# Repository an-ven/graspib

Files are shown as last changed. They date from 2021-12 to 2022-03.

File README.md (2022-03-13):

# GrasPiB
GPIB interface board for Raspberry Pi, designed to work with [linux-gpib](https://linux-gpib.sourceforge.io/) gpio bitbang driver. Extra features include: RS232 serial interface, voltage regulator, fan mount and I2C conector.

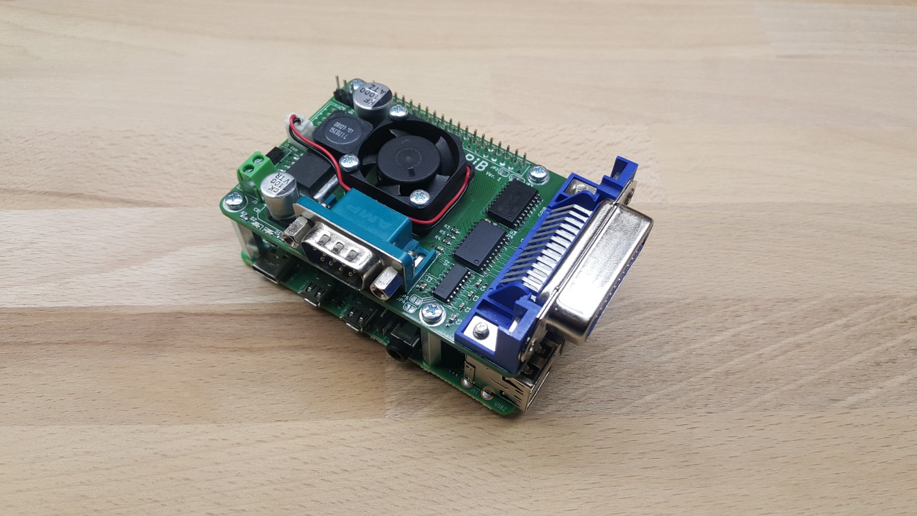
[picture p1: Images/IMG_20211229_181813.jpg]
GrasPiB


## Features
* Active GPIB interface circuit using SN7516x bus driver ICs
* RS232 serial interface (MAX3232 level converter), with optionally configurable RTS and CTS lines
* Step down voltage regulator (LM2576) for use with higher voltage power supplies (7-35VDC)
* 25mm cooling fan mounting holes and 2pin JST-PH connector for power
* I2C break out connector with one extra GPIO line (5pin JST-PH connector)
* Stacks on top of a Raspberry Pi

## Configuration options

**JP7 Power supply selection:**

* Close pins 1-2: Power from J5 screw terminal trough onboard regulator circuit (7-35VDC input)
* Close pins 2-3: Power from J5 screw terminal bypassing onboard regulator circuit (5VDC input only !!)
* Leave Open: Power from Raspberry Pi power input USB connector, GrasPiB regulator circuit is isolated

**JP6 Output Voltage select on I2C breakout connector**

* Close pins 1-2: 3,3V on J4 pin 1
* Close pins 2-3: 5V on J4 pin 1

**Enabling RS232 CTS and RTS lines:**

* Close jumpers JP1, JP2, JP4 and JP5, open JP3 positions 1-2 and close positions 2-3
* This change also needs the GPIB DIO3 signal to be reassigned from GPIO16 to GPIO21 (linux-gpib driver code modifications needed)

## Linux-gpib setup instructions

(following instructions were tested on a fresh Raspberry Pi OS Lite image)

0. Setup and configure OS on Raspberry Pi
    * Do as you would with a fresh OS image (passwords, networking, services, communication ports...)

1. Install build tools and dependencies
    * Build tools: `$ sudo apt install build-essential autoconf automake libtool flex bison`
    * RPi kernel headers: `$ sudo apt install raspberrypi-kernel-headers`
    * Python3 headers: `$ sudo apt install python3-dev`

2. Download linux-gpib source files
    * Get release archives (4.3.4 or later) from [https://sourceforge.net/projects/linux-gpib/files](https://sourceforge.net/projects/linux-gpib/files)
    * or get the latest source from [https://sourceforge.net/p/linux-gpib/code/HEAD/tree/](https://sourceforge.net/p/linux-gpib/code/HEAD/tree/)

3. Build and install kernel drivers
    * Enter linux-gpib-kernel directory `$ cd linux-gpib-src-dir/linux-gpib-kernel`
    * Build kernel module by running make `$ make`
    * Install kernel module `$ sudo make install`
    * Update kernel module list `$ sudo depmod -a`
    * Load gpib_bitbang kernel module `$ sudo modprobe gpib_bitbang`
    * Now there should be some `gpib*` devices in `/dev`
    * Make the module loads on boot by adding `gpib_bitbang` line to `/etc/modules-load.d/modules.conf`

**When Raspberry Pi OS kernel gets upgraded, linux-gpib kernel module also needs to be rebuilt and reinstalled.**
Basically just repeat above `make` and `make install` steps when kernel gets upgraded...

4. Build and install user space tools
    * Enter linux-gpib-user directory: `$ cd linux-gpib-src-dir/linux-gpib-user`
    * If building from svn checkout first run bootstrap script: `$ ./bootstrap`
    * Run configure script: `$ ./configure` (run `$ ./configure --help` to list additional options)
    * Build user space tools by running make: `$ make`
    * Install user space tools: `$ sudo make install`
    * Make sure that shared library directory (default: `/usr/local/lib/`) is listed in: `/etc/ld.so.conf.d/`
    * Then run: `$ sudo ldconfig`

5. Configure GPIB interface
    * Open gpib.conf configuration file `$ sudo nano /usr/local/etc/gpib.conf` (default location)
    * Set `board_type = "gpib_bitbang"` and other relevant settings (for details refer to included [`gpib.conf`](extra/gpib.conf) file, [linux-gpib documentetion](https://linux-gpib.sourceforge.io/doc_html/configuration-gpib-conf.html) and included template file `linux-gpib-src-dir/linux-gpib-user/util/template/gpib.conf`)
    * Run gpib_config so the driver reads the configuration file `$ sudo gpib_config --minor 0`
    * Make the last command execute on every startup using crontab entry:
        - Edit crontab for root user: `$ sudo crontab -e`
        - Add line the following line to cron tab file: `@reboot /usr/local/sbin/gpib_config --minor 0`

6. Enable non root users to use GPIB interface without sudo
    - Add new `gpib` system group: `$ sudo groupadd -r gpib`
    - Append your_user_name to `gpib` supplementary group: `$ sudo usermod -a -G gpib your_user_name`
    - Create [`/etc/udev/rules.d/99-gpib.rules`](extra/99-gpib.rules) file and add line: `SUBSYSTEM=="gpib_common", GROUP="gpib", MODE="0660"`
    - Reboot system to apply changes (udevadm utility can also be used, but reboot is dead simple to remember)
    - Test by running `ibtest` without sudo

Above instructions should result in an environment with a functional GPIB interface, C headers and python bindings, ready for use.

## Enabling RS232 Hardware flow control

### Hardware setup:

On the Raspberry Pi CTS and RTS signals are mapped to pins GPIO16 and GPIO17. By default, linux-gpib bitbang driver uses GPIO16 for GPIB DIO3 signal. In order to free up GPIO16, the DIO3 signal can be rewired to GPIO21 by **opening** positions **1-2** (cut traces between pads) and **closing** positions **2-3** on the solder jumper JP3.

By default, CTS and RTS signals are disconnected from the RS232 level converter chip. To connect the CTS and RTS lines, solder jumpers **JP1**, **JP2**, **LP4** and **JP5** need to be **closed**.

Note also, that the extra GPIO17 line on the I2C break out connector J4 can't be used for other purposes when system is configured for RS232 hardware flow control.

### Software setup:

1. Because GPIB signal DIO3 was rewired in hardware to GPIO21, this change needs to reflected in the linux-gpib bitbang driver source code. The source file in question is: `[linux-gpib-sorce-dir]/linux-gpib-kernel/drivers/gpib/gpio/gpib_bitbang.c`, where the signal pairing section needs to be modified as shown below. With the modification done, the linux-gpib driver needs to be compiled as described in step 3 of the "Linux-gpib setup instructions" section of this document.

```
/**********************************************
 *  Signal pairing and pin wiring between the *
 *  Raspberry-Pi connector and the GPIB bus   *
 *                                            *
 *               signal           pin wiring  *
 *            GPIB  Pi-gpio     GPIB  ->  RPi *
**********************************************/
typedef enum {
        D01_pin_nr =  20,     /*   1  ->  38  */
        D02_pin_nr =  26,     /*   2  ->  37  */
//      D03_pin_nr =  16,     /*   3  ->  36  ORIGINAL AND COMMENTED OUT */
        D03_pin_nr =  21,     /*   3  ->  40  MODIFIED TO AVOID CONFLICT WITH CTS SIGNAL */
        D04_pin_nr =  19,     /*   4  ->  35  */
        D05_pin_nr =  13,     /*  13  ->  33  */
        D06_pin_nr =  12,     /*  14  ->  32  */
        D07_pin_nr =   6,     /*  15  ->  31  */
        D08_pin_nr =   5,     /*  16  ->  29  */
        EOI_pin_nr =   9,     /*   5  ->  21  */
        DAV_pin_nr =  10,     /*   6  ->  19  */
        NRFD_pin_nr = 24,     /*   7  ->  18  */
        NDAC_pin_nr = 23,     /*   8  ->  16  */
        IFC_pin_nr =  22,     /*   9  ->  15  */
        SRQ_pin_nr =  11,     /*  10  ->  23  */
        _ATN_pin_nr = 25,     /*  11  ->  22  */
        REN_pin_nr =  27,     /*  17  ->  13  */
...

```

2. Next the [`uart-ctsrts.dtbo`](extra/uart-ctsrts.dtbo) file (included in extra directory) needs to be copied in to the `/boot/overlays` directory and add the following lines need to be added to the `/boot/config.txt` file:

```
enable_uart=1
dtoverlay=disable-bt
dtoverlay=uart-ctsrts
```

3. Reboot the system to apply changes.

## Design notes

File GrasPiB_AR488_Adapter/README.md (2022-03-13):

# GrasPiB Arduino Micro adapter

A simple adapter board for connecting the GrasPiB Raspberry Pi hat to an Arduino Micro running the [AR488 firmware](https://github.com/Twilight-Logic/AR488).

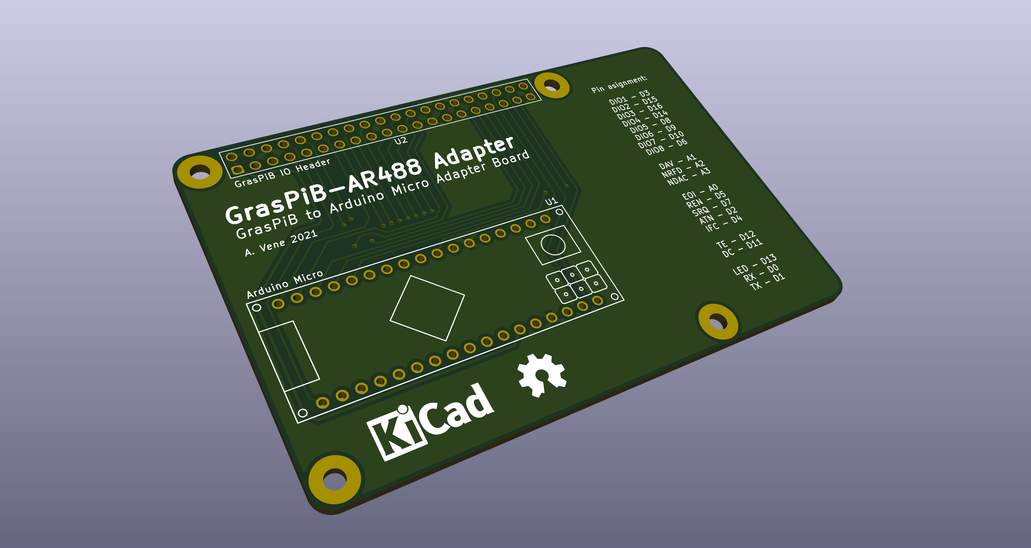
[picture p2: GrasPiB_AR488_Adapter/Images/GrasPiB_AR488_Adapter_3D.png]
GrasPiB_AR488_Adapter


## AR488 configuration

Pin assignment is compatible with the default AR488, except for the TE and DC control signals for the SN7516x bus drivers, which need to be enabled in the [`AR488_Config.h`](https://github.com/Twilight-Logic/AR488/blob/db879376f8afdc95d7bf1696cdb96f927a3bf9c9/src/AR488/AR488_Config.h) file.

In the `AR488_Config.h` config file, search for the `Enable SN7516x chips` section and modify it as follows:

```
/***** Enable SN7516x chips *****/
/*
 * Uncomment to enable the use of SN7516x GPIB tranceiver ICs.
 * This will require the use of an additional GPIO pin to control
 * the read and write modes of the ICs.
 */
#define SN7516X
#ifdef SN7516X
  #define SN7516X_TE 12
  #define SN7516X_DC 11
  //#define SN7516X_SC 12
#endif
```

No other modifications should be needed to use GrasPiB with an Arduino and AR488 software.

## Signal mapping

```
GrasPiB - AR488

   DIO1 - D3
   DIO2 - D15
   DIO3 - D16
   DIO4 - D14
   DIO5 - D8
   DIO6 - D9
   DIO7 - D10
   DIO8 - D6

    DAV - A1
   NRFD - A2
   NDAC - A3

    EOI - A0
    REN - D5
    SRQ - D7
    ATN - D2
    IFC - D4

     TE - D12
     DC - D11

    LED - D13
     RX - D0
     TX - D1
```

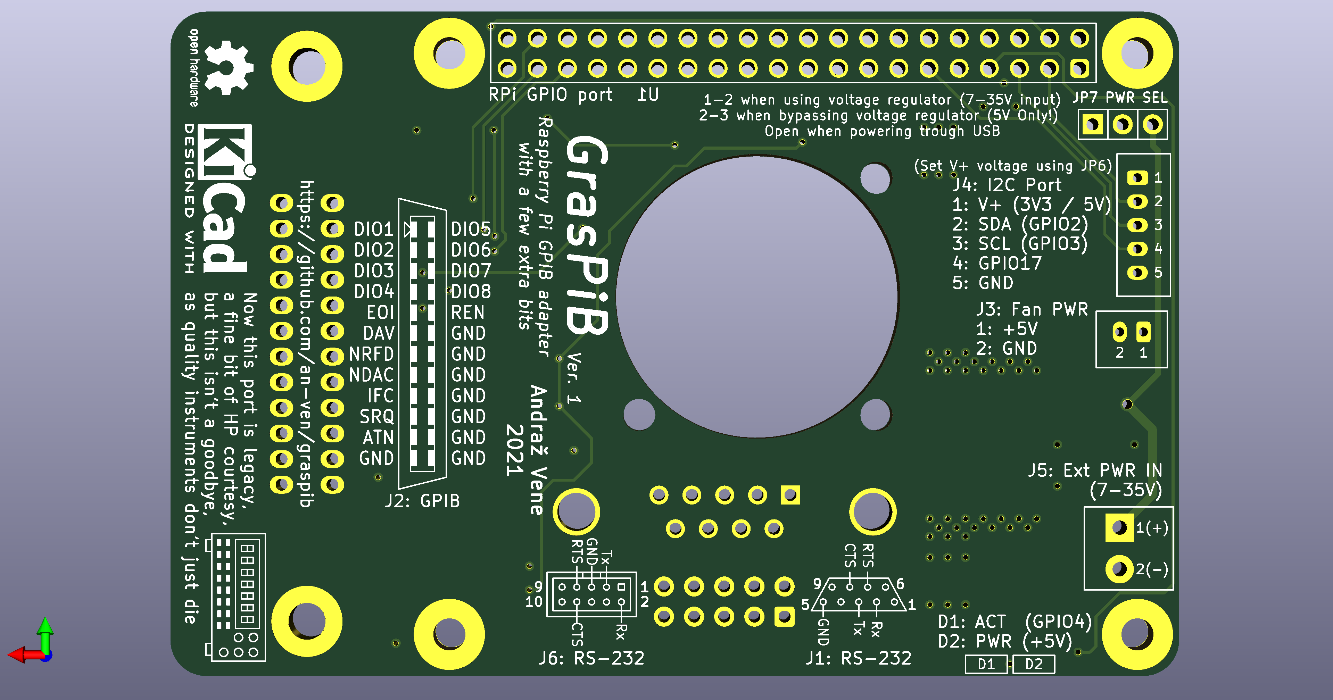
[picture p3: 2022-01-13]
Images/GrasPiB_v1_Back.png

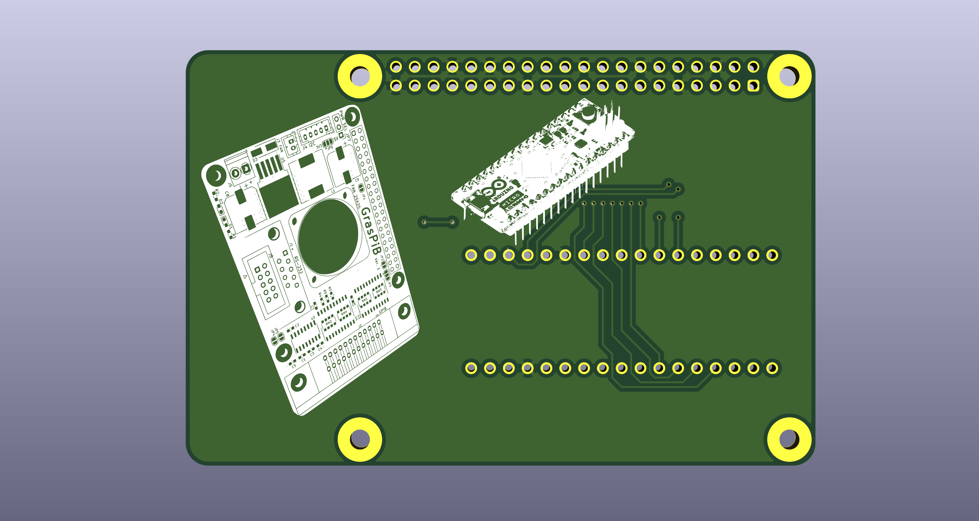
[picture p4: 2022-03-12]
GrasPiB_AR488_Adapter/Images/GrasPiB_AR488_Adapter_Back.png

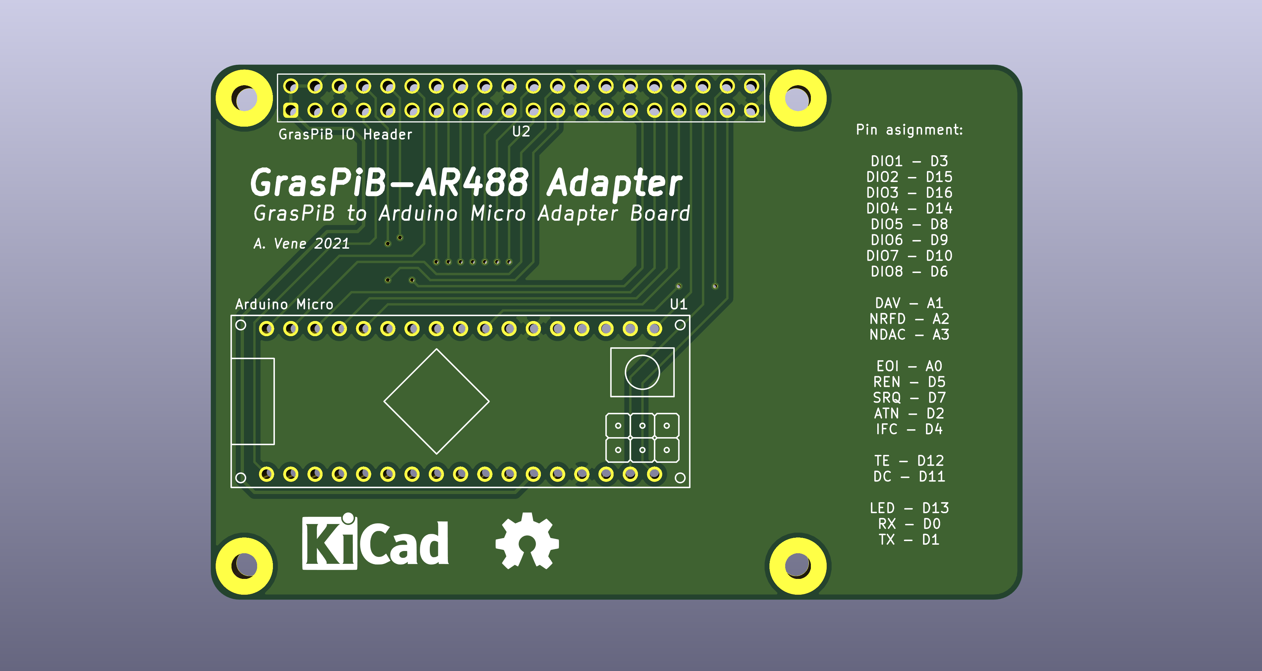
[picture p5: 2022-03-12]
GrasPiB_AR488_Adapter/Images/GrasPiB_AR488_Adapter_Front.png

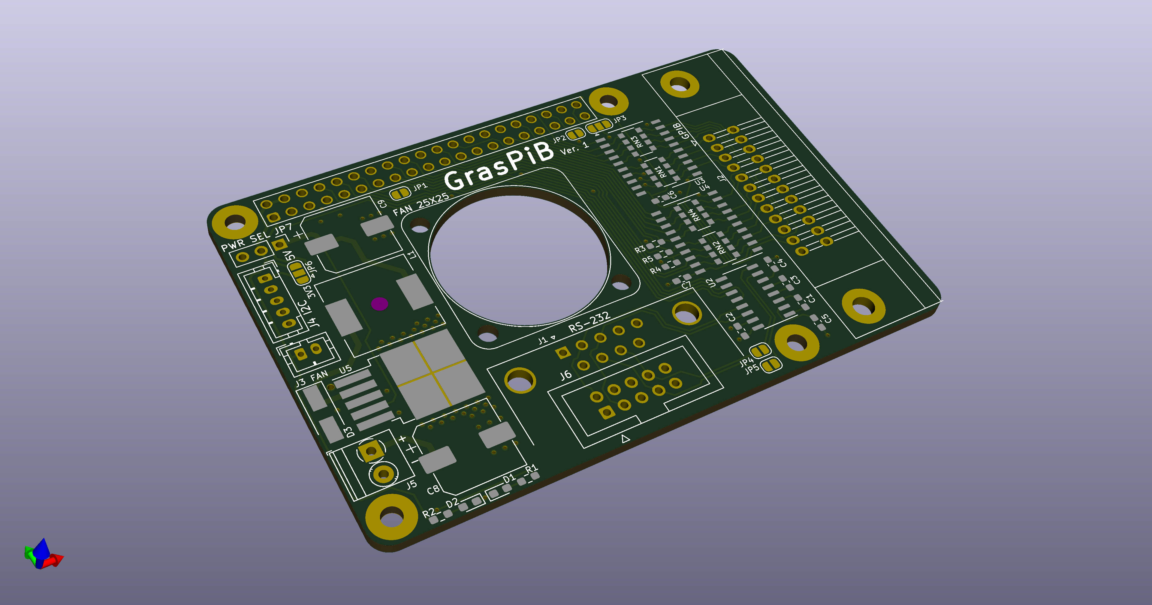
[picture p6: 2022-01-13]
Images/GrasPiB_v1_3D.png

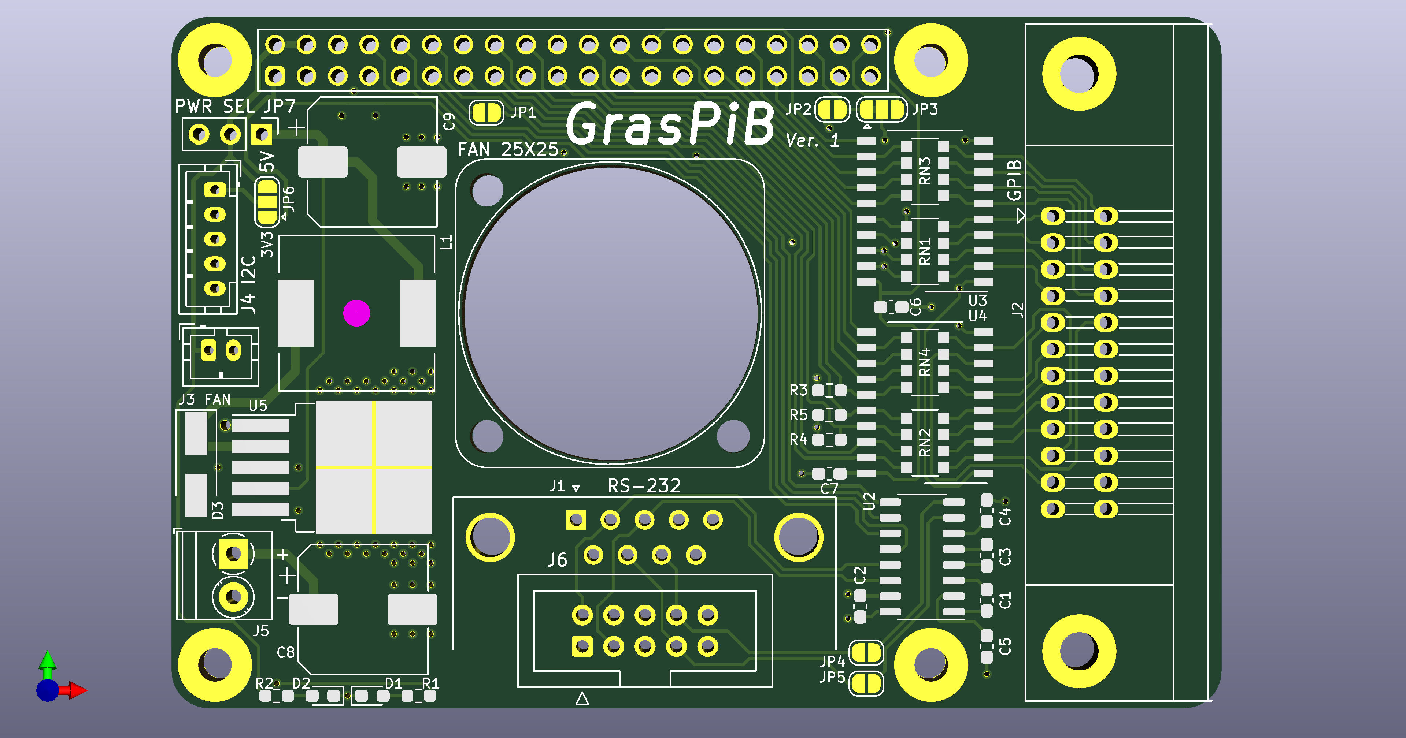
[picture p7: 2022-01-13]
Images/GrasPiB_v1_Front.png

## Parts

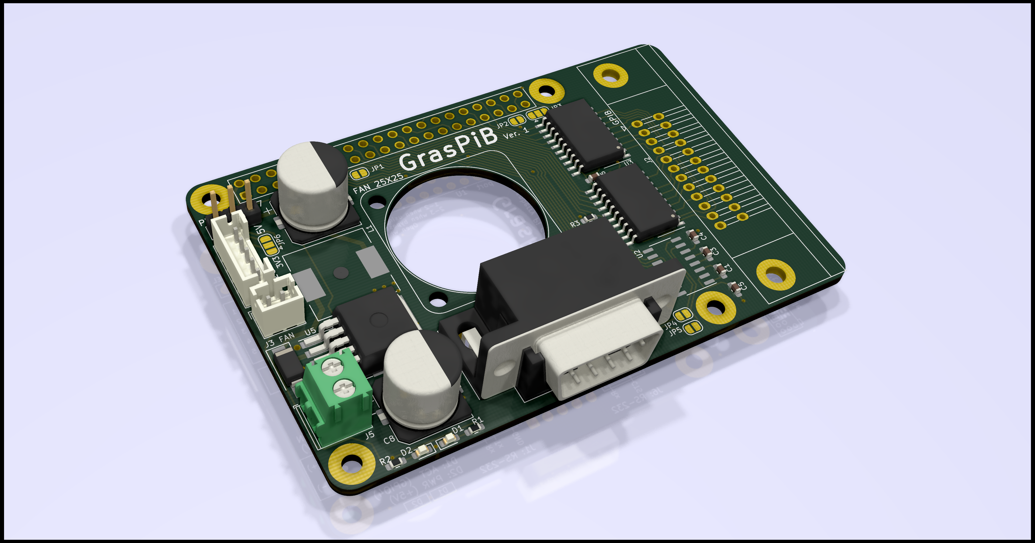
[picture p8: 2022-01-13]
Images/GrasPiB_v1_3D_components.png

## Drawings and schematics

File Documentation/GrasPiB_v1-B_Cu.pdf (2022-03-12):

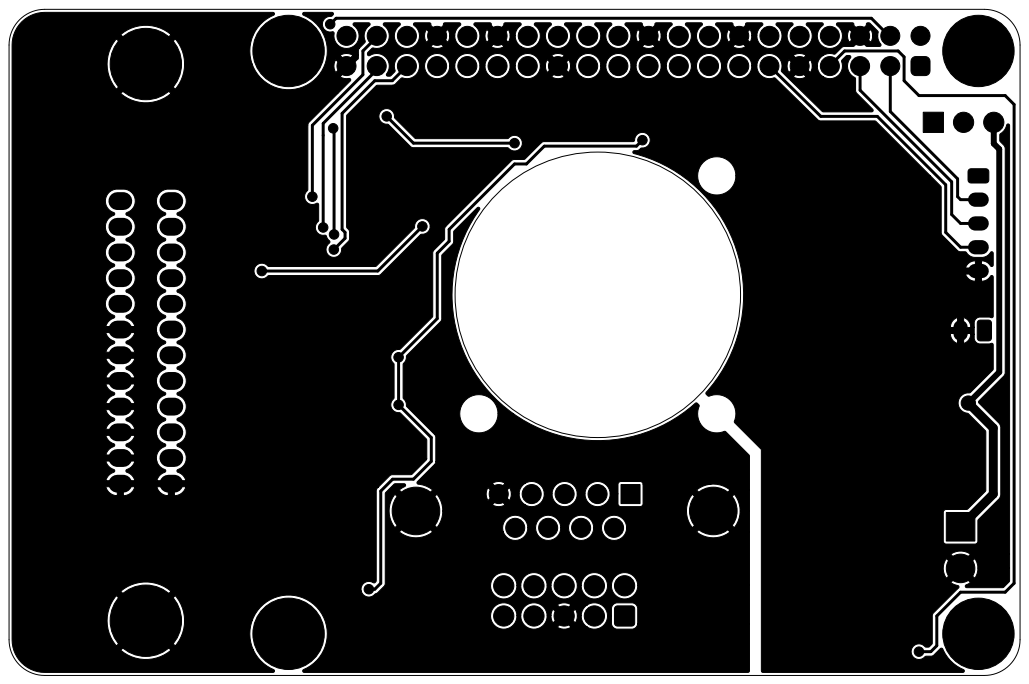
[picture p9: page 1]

Raspberry Pi GPIB, RS232 and Power supply HAT

https://github.com/an-ven/graspib
File: GrasPiB_v1.kicad_pcb Sheet: þÿAndra~ Vene

Id: 1/1 Title: GrasPiB - Ver. 1

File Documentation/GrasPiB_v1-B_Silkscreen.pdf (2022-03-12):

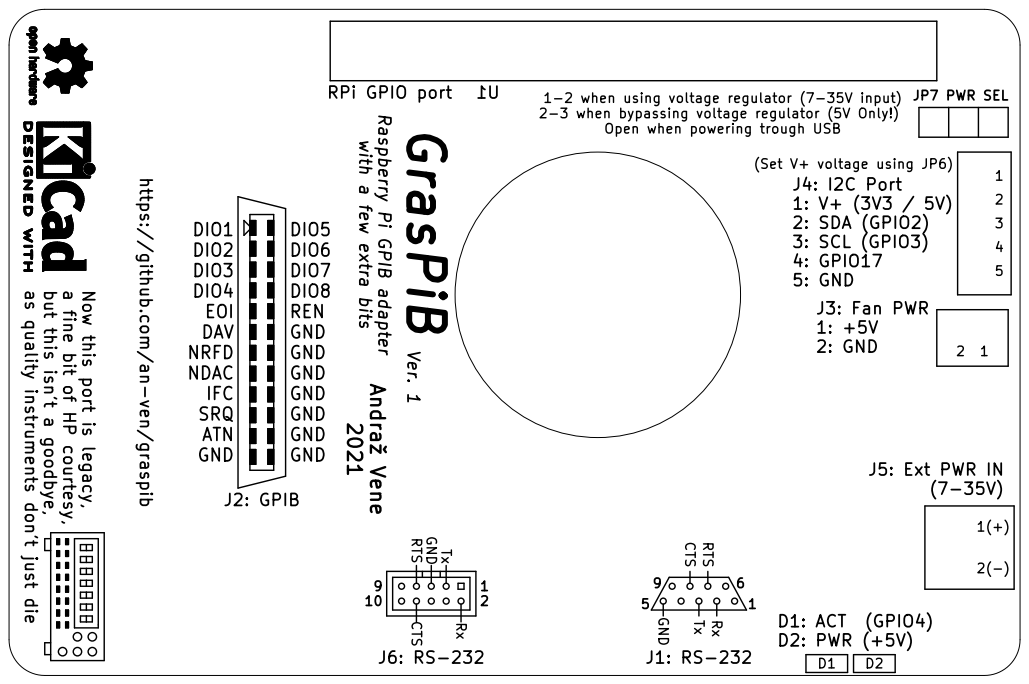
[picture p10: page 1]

4 RPi GPIO port DIO1 DIO2 DIO3 DIO4 EOI DAV NRFD
2 D1: ACT (GPIO4) D2: PWR (+5V)J5: Ext PWR IN

1-2 when using voltage regulator (7-35V input) 2-3 when bypassing voltage regulator (5V Only!) Open when powering trough USB U1

(Set V+ voltage using JP6) JP7 PWR SEL

(7-35V) DIO5 DIO6 DIO7 DIO8 REN GND GND GND GND GND GND GND

Raspberry Pi GPIB, RS232 and Power supply HAT

https://github.com/an-ven/graspib
File: GrasPiB_v1.kicad_pcb Sheet: þÿAndra~ Vene

Id: 1/1 Title: GrasPiB - Ver. 1

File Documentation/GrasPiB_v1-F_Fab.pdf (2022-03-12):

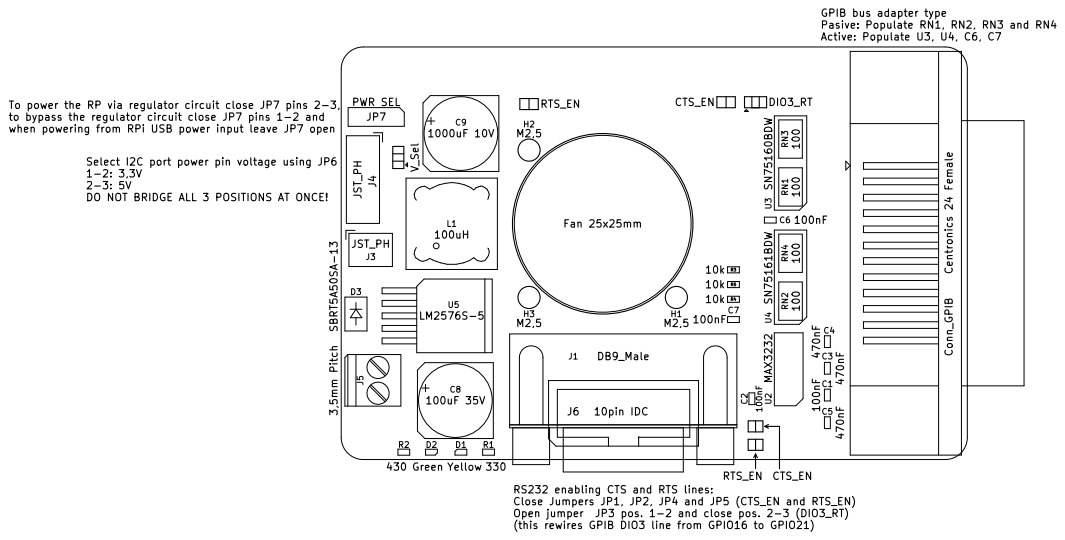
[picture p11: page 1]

To power the RP via regulator circuit close JP7 pins 2-3, to bypass the regulator circuit close JP7 pins 1-2 and when powering from RPi USB power input leave JP7 open Select I2C port power pin voltage using JP6

RS232 enabling CTS and RTS lines: Close Jumpers JP1, JP2, JP4 and JP5 (CTS_EN and RTS_EN) Open jumper JP3 pos. 1-2 and close pos. 2-3 (DIO3_RT)

Raspberry Pi GPIB, RS232 and Power supply HAT

https://github.com/an-ven/graspib
File: GrasPiB_v1.kicad_pcb Sheet: þÿAndra~ Vene

Id: 1/1 Title: GrasPiB - Ver. 1

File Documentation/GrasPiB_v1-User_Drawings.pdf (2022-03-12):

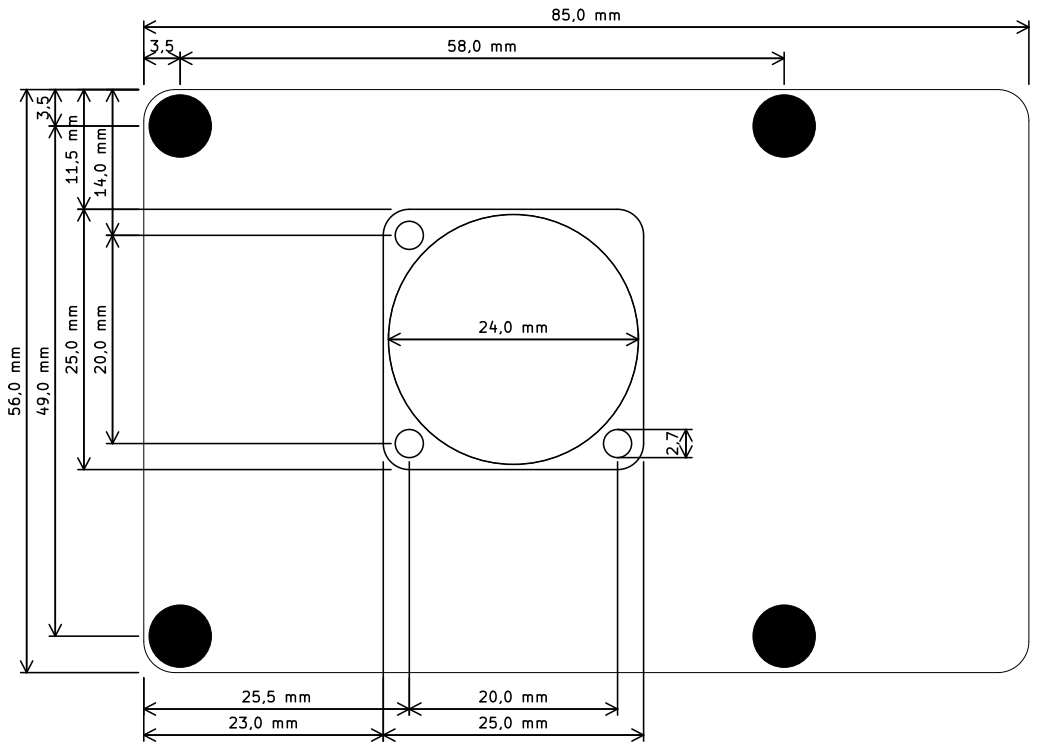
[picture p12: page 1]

Raspberry Pi GPIB, RS232 and Power supply HAT 56,0 mm

https://github.com/an-ven/graspib
File: GrasPiB_v1.kicad_pcb Sheet: þÿAndra~ Vene

Id: 1/1 Title: GrasPiB - Ver. 1

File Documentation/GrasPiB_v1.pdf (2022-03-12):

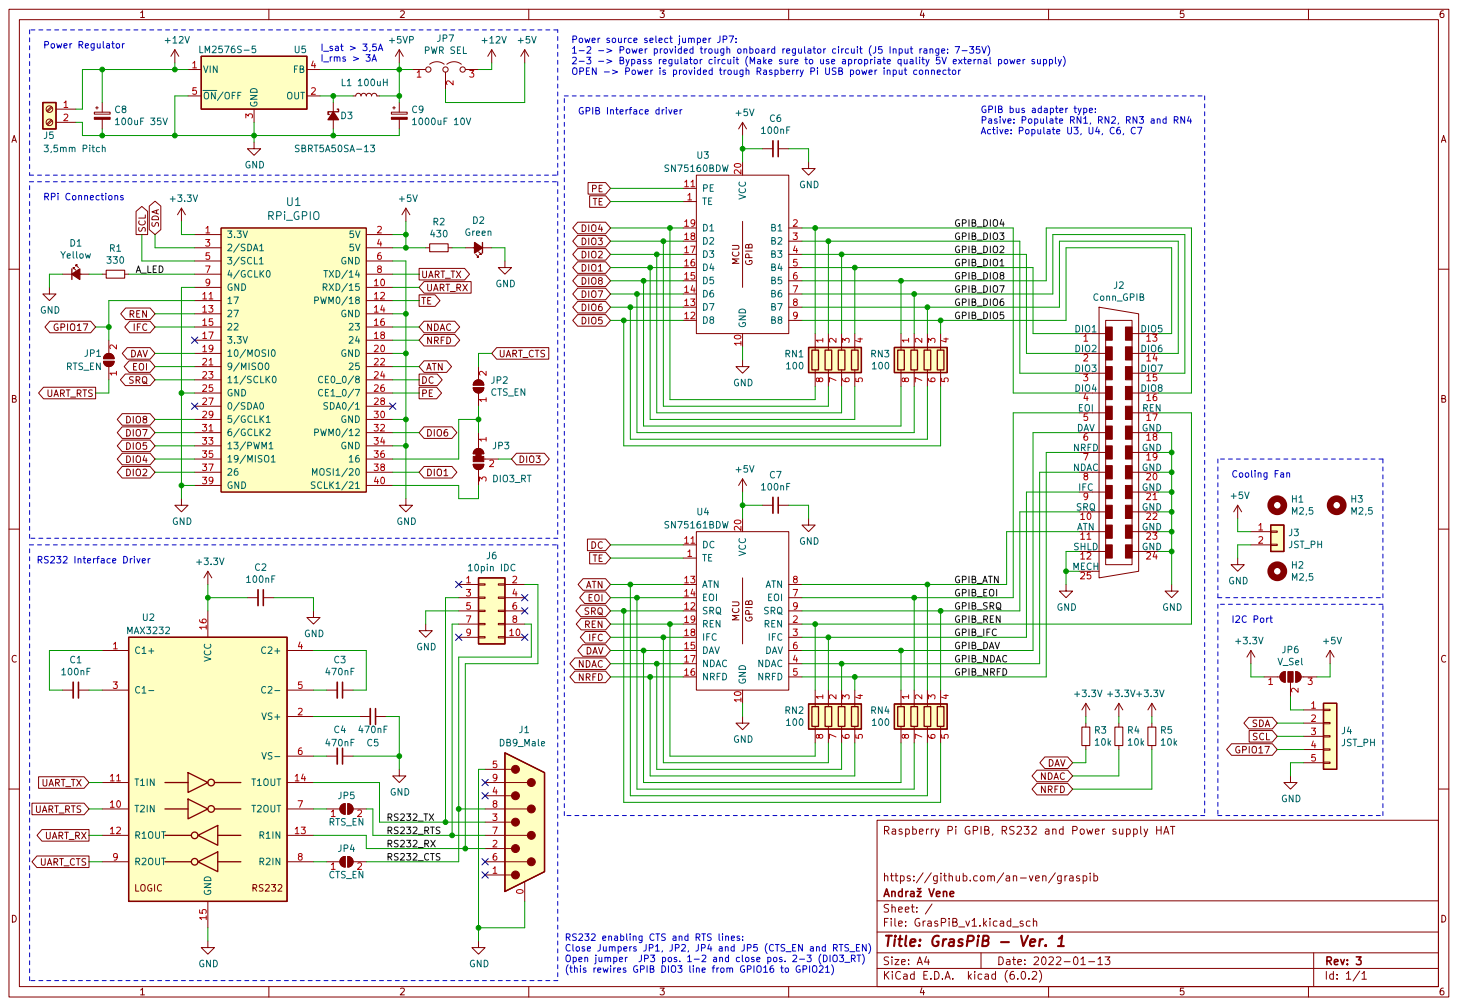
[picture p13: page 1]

Power source select jumper JP7:
1-2 -> Power provided trough onboard regulator circuit (J5 Input range: 7-35V)
2-3 -> Bypass regulator circuit (Make sure to use apropriate quality 5V external power supply)
OPEN -> Power is provided trough Raspberry Pi USB power input connector

8 IFC | 20 GND
9 | 21 GND
10 ATN | 22 GND

I2C Port

Raspberry Pi GPIB, RS232 and Power supply HAT

https://github.com/an-ven/graspib
File: GrasPiB_v1.kicad_sch Sheet: / þÿAndra~ Vene

Id: 1/1 Title: GrasPiB - Ver. 1

Close Jumpers JP1, JP2, JP4 and JP5 (CTS_EN and RTS_EN)
Open jumper JP3 pos. 1-2 and close pos. 2-3 (DIO3_RT)
(this rewires GPIB DIO3 line from GPIO16 to GPIO21)

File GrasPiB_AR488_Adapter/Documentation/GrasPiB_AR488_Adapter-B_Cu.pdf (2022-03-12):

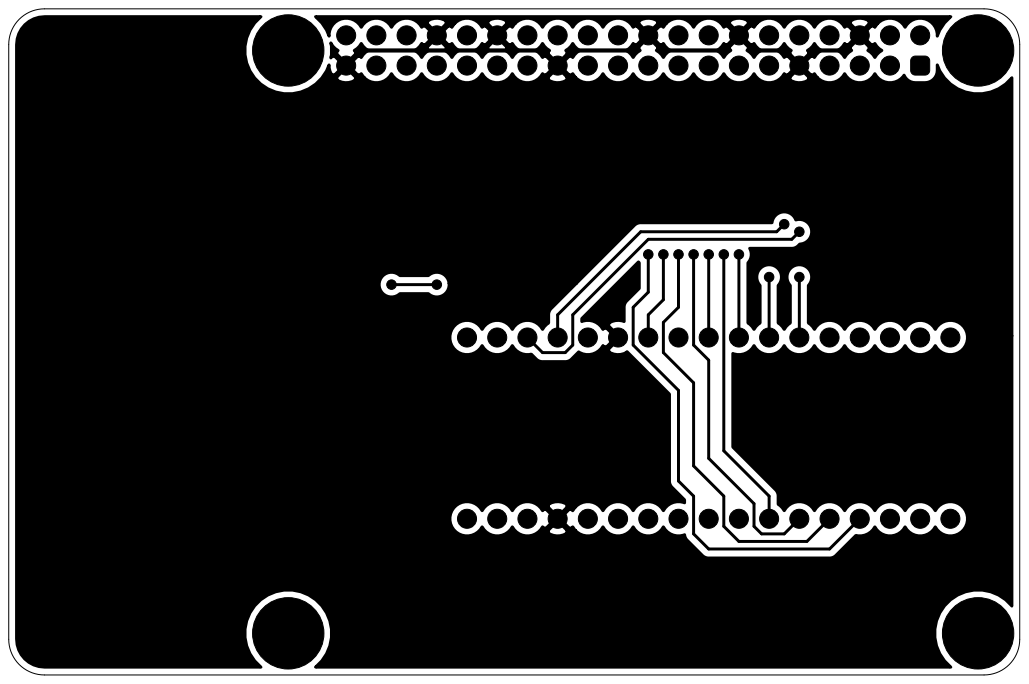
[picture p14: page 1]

File: GrasPiB_AR488_Adapter.kicad_pcb Sheet: A. Vene GrasPiB to Arduino Micro Adapter Board

Id: 1/1 Title: GrasPiB-AR488 Adapter

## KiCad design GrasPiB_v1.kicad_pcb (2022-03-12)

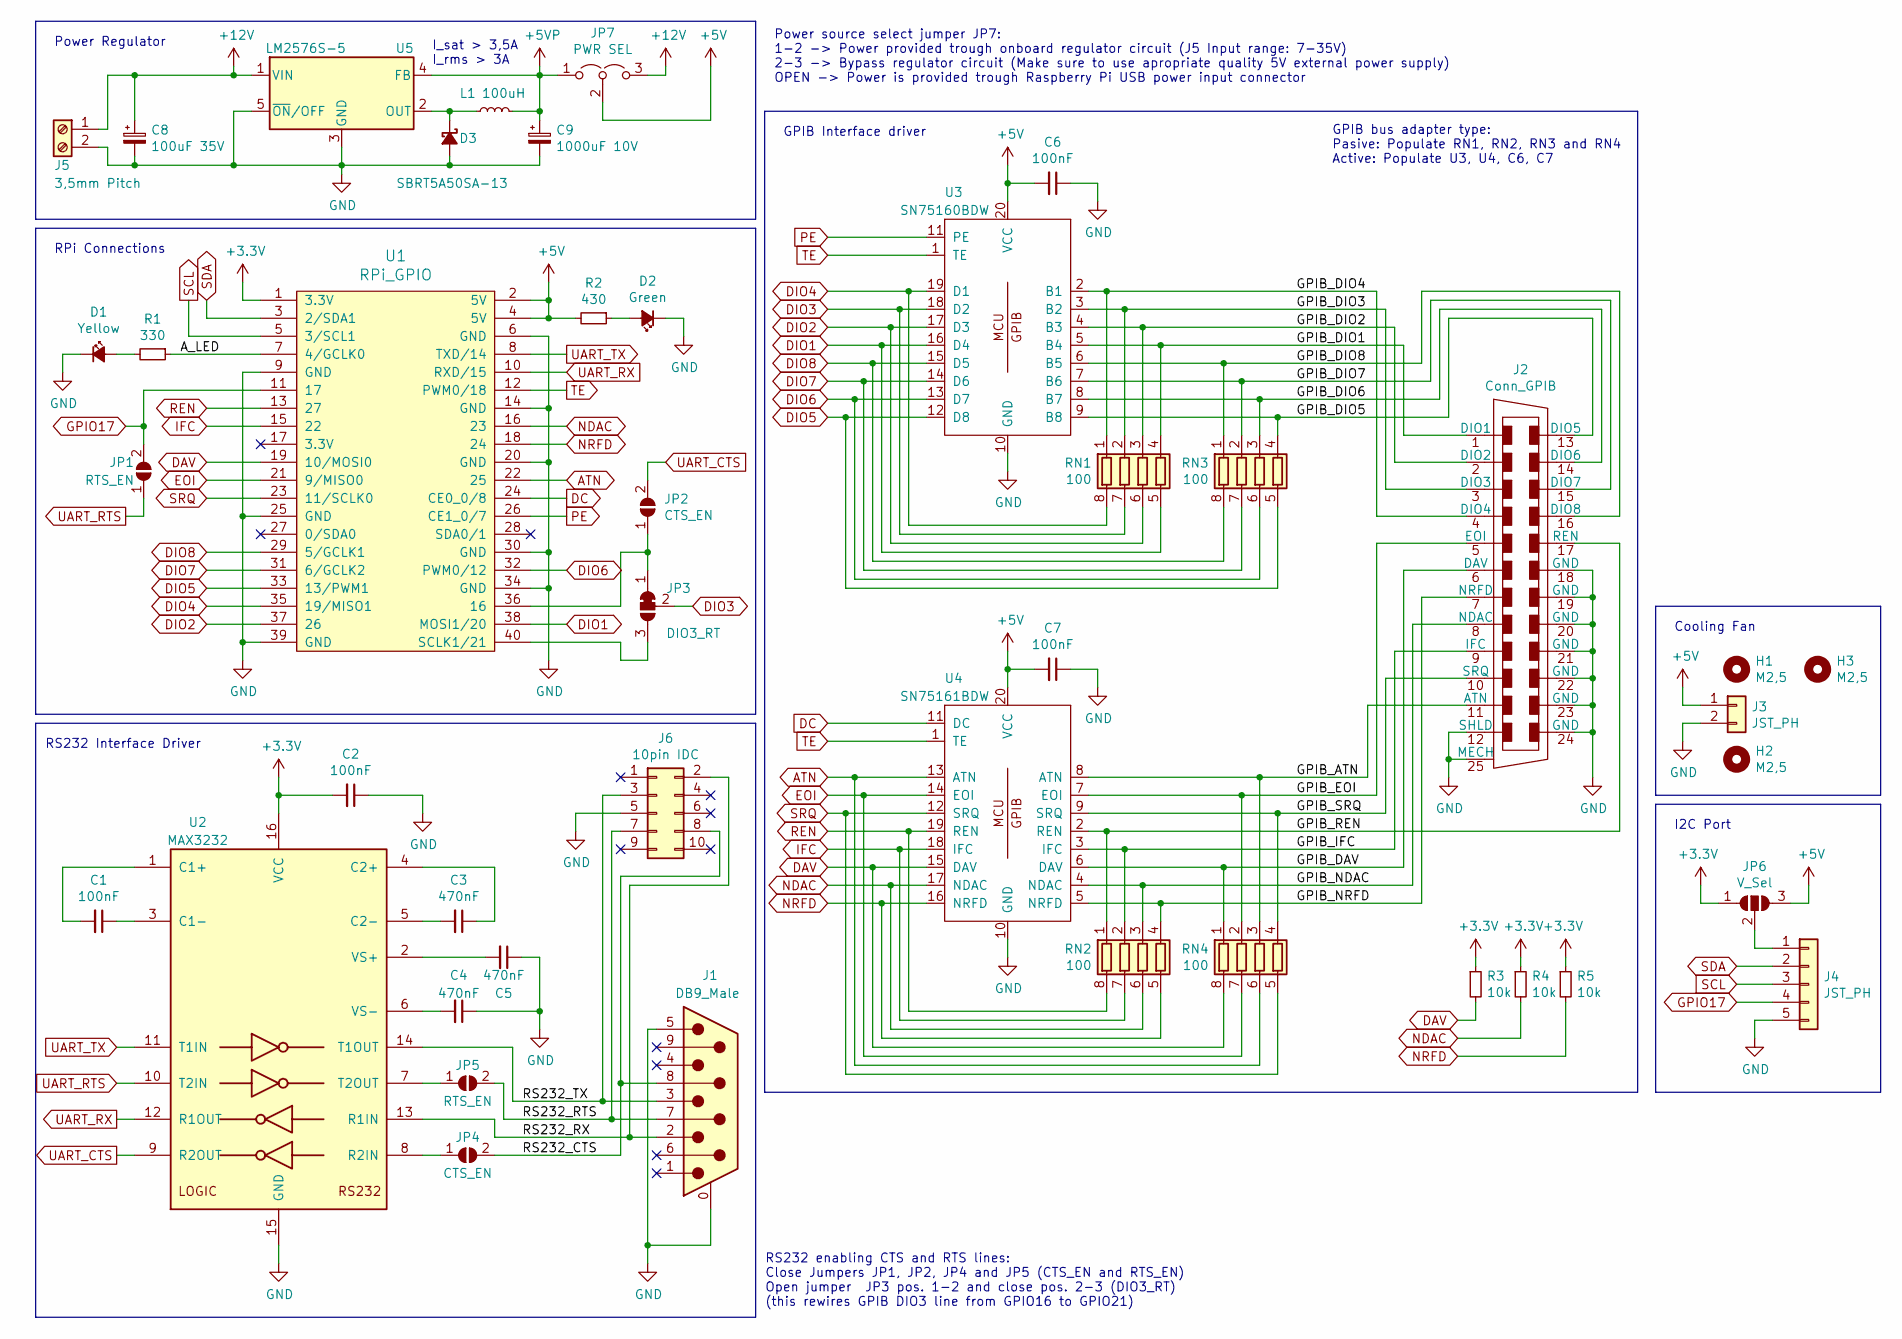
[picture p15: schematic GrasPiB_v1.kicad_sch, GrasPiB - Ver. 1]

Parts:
C1, C2, C6, C7: 100nF; C_0603_1608Metric_Pad1.08x0.95mm_HandSolder
C3, C4, C5: 470nF; C_0603_1608Metric_Pad1.08x0.95mm_HandSolder
C8: 100uF 35V; CP_Elec_10x10
C9: 1000uF 10V; CP_Elec_10x10
D1: Yellow; LED_0603_1608Metric_Pad1.05x0.95mm_HandSolder
D2: Green; LED_0603_1608Metric_Pad1.05x0.95mm_HandSolder
D3: SBRT5A50SA-13; D_SMA_Handsoldering
H1, H2, H3: M2,5; MountingHole_2.7mm_M2.5
J1: DB9_Male; DSUB-9_Male_Horizontal_P2.77x2.84mm_EdgePinOffset7.70mm_Hou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
J2: Conn_GPIB; NorComp_112-024-213R001
J3: JST_PH; JST_PH_B2B-PH-K_1x02_P2.00mm_Vertical
J4: JST_PH; JST_PH_B5B-PH-K_1x05_P2.00mm_Vertical
J5: 3,5mm Pitch; TerminalBlock_Phoenix_PT-1,5-2-3.5-H_1x02_P3.50mm_Horizontal
J6: 10pin IDC; IDC-Header_2x05_P2.54mm_Vertical
JP1, JP5: RTS_EN; SolderJumper-2_P1.3mm_Open_RoundedPad1.0x1.5mm
JP2, JP4: CTS_EN; SolderJumper-2_P1.3mm_Open_RoundedPad1.0x1.5mm
JP3: DIO3_RT; SolderJumper-3_P1.3mm_Bridged12_RoundedPad1.0x1.5mm
JP6: V_Sel; SolderJumper-3_P1.3mm_Open_RoundedPad1.0x1.5mm
JP7: PWR SEL; PinHeader_1x03_P2.54mm_Vertical
L1: 100uH; L_Wuerth_WE-PD-Typ-LS
R1: 330; R_0603_1608Metric_Pad0.98x0.95mm_HandSolder
R2: 430; R_0603_1608Metric_Pad0.98x0.95mm_HandSolder
R3, R4, R5: 10k; R_0603_1608Metric_Pad0.98x0.95mm_HandSolder
RN1, RN2, RN3, RN4: 100; R_Array_Convex_4x1206
U1: RPi_GPIO; RPi4_Hat
U2: MAX3232; SO-16_3.9x9.9mm_P1.27mm
U3: SN75160BDW; SO-20_12.8x7.5mm_P1.27mm
U4: SN75161BDW; SO-20_12.8x7.5mm_P1.27mm
U5: LM2576S-5; TO-263-5_TabPin3

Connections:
+3V3: C2.2, JP6.1 (A), R3.1, R4.1, R5.1, U1.1 (3.3V), U2.16 (VCC)
+5V: C6.2, C7.2, J3.1, JP6.3 (B), JP7.2 (C), R2.2, U1.2 (5V), U1.4 (5V), U3.20 (VCC), U4.20 (VCC)
+5VP: C9.1, JP7.1 (A), L1.2, U5.4 (FB)
+12V: C8.1, J5.1, JP7.3 (B), U5.1 (VIN)
/A_LED: R1.1, U1.7 (4/GCLK0)
/GPIB_ATN: J2.11 (ATN), RN4.3 (R3.1), U4.8 (ATN)
/GPIB_DAV: J2.6 (DAV), RN4.1 (R1.1), U4.6 (DAV)
/GPIB_DIO1: J2.1 (DIO1), RN1.4 (R4.1), U3.5 (B4)
/GPIB_DIO2: J2.2 (DIO2), RN1.3 (R3.1), U3.4 (B3)
/GPIB_DIO3: J2.3 (DIO3), RN1.2 (R2.1), U3.3 (B2)
/GPIB_DIO4: J2.4 (DIO4), RN1.1 (R1.1), U3.2 (B1)
/GPIB_DIO5: J2.13 (DIO5), RN3.4 (R4.1), U3.9 (B8)
/GPIB_DIO6: J2.14 (DIO6), RN3.3 (R3.1), U3.8 (B7)
/GPIB_DIO7: J2.15 (DIO7), RN3.2 (R2.1), U3.7 (B6)
/GPIB_DIO8: J2.16 (DIO8), RN3.1 (R1.1), U3.6 (B5)
/GPIB_EOI: J2.5 (EOI), RN4.2 (R2.1), U4.7 (EOI)
/GPIB_IFC: J2.9 (IFC), RN2.2 (R2.1), U4.3 (IFC)
/GPIB_NDAC: J2.8 (NDAC), RN2.3 (R3.1), U4.4 (NDAC)
/GPIB_NRFD: J2.7 (NRFD), RN2.4 (R4.1), U4.5 (NRFD)
/GPIB_REN: J2.17 (REN), RN2.1 (R1.1), U4.2 (REN)
/GPIB_SRQ: J2.10 (SRQ), RN4.4 (R4.1), U4.9 (SRQ)
/RS232_CTS: J1.8, J6.8, JP4.2 (B)
/RS232_RTS: J1.7, J6.7, JP5.2 (B)
/RS232_RX: J1.2, J6.2, U2.13 (R1IN)
/RS232_TX: J1.3, J6.3, U2.14 (T1OUT)
ATN: RN4.6 (R3.2), U1.22 (25), U4.13 (ATN)
DAV: R3.2, RN4.8 (R1.2), U1.19 (10/MOSI0), U4.15 (DAV)
DC: U1.24 (CE0_0/8), U4.11 (DC)
DIO1: RN1.5 (R4.2), U1.38 (MOSI1/20), U3.16 (D4)
DIO2: RN1.6 (R3.2), U1.37 (26), U3.17 (D3)
DIO3: JP3.2 (C), RN1.7 (R2.2), U3.18 (D2)
DIO4: RN1.8 (R1.2), U1.35 (19/MISO1), U3.19 (D1)
DIO5: RN3.5 (R4.2), U1.33 (13/PWM1), U3.12 (D8)
DIO6: RN3.6 (R3.2), U1.32 (PWM0/12), U3.13 (D7)
DIO7: RN3.7 (R2.2), U1.31 (6/GCLK2), U3.14 (D6)
DIO8: RN3.8 (R1.2), U1.29 (5/GCLK1), U3.15 (D5)
EOI: RN4.7 (R2.2), U1.21 (9/MISO0), U4.14 (EOI)
GND: C2.1, C4.1, C5.1, C6.1, C7.1, C8.2, C9.2, D1.1 (K), D2.1 (K), D3.2 (A), J1.0 (PAD), J1.5, J2.12 (SHLD), J2.18 (GND), J2.19 (GND), J2.20 (GND), J2.21 (GND), J2.22 (GND), J2.23 (GND), J2.24 (GND), J2.25 (MECH), J3.2, J4.5, J5.2, J6.5, U1.6 (GND), U1.9 (GND), U1.14 (GND), U1.20 (GND), U1.25 (GND), U1.30 (GND), U1.34 (GND), U1.39 (GND), U2.15 (GND), U3.10 (GND), U4.10 (GND), U5.3 (GND), U5.5 (~ON/OFF)
GPIO17: J4.4, JP1.2 (B), U1.11 (17)
IFC: RN2.7 (R2.2), U1.15 (22), U4.18 (IFC)
NDAC: R4.2, RN2.6 (R3.2), U1.16 (23), U4.17 (NDAC)
NRFD: R5.2, RN2.5 (R4.2), U1.18 (24), U4.16 (NRFD)
unnamed: C1.1, U2.3 (C1-)
unnamed: C1.2, U2.1 (C1+)
unnamed: C3.1, U2.4 (C2+)
unnamed: C3.2, U2.5 (C2-)
unnamed: C4.2, U2.6 (VS-)
unnamed: C5.2, U2.2 (VS+)
unnamed: D1.2 (A), R1.2
unnamed: D2.2 (A), R2.1
unnamed: D3.1 (K), L1.1, U5.2 (OUT)
unnamed: J4.1, JP6.2 (C)
unnamed: JP2.1 (A), JP3.1 (A), U1.36 (16)
unnamed: JP3.3 (B), U1.40 (SCLK1/21)
unnamed: JP4.1 (A), U2.8 (R2IN)
unnamed: JP5.1 (A), U2.7 (T2OUT)
PE: U1.26 (CE1_0/7), U3.11 (PE)
REN: RN2.8 (R1.2), U1.13 (27), U4.19 (REN)
SCL: J4.3, U1.5 (3/SCL1)
SDA: J4.2, U1.3 (2/SDA1)
SRQ: RN4.5 (R4.2), U1.23 (11/SCLK0), U4.12 (SRQ)
TE: U1.12 (PWM0/18), U3.1 (TE), U4.1 (TE)
UART_CTS: JP2.2 (B), U2.9 (R2OUT)
UART_RTS: JP1.1 (A), U2.10 (T2IN)
UART_RX: U1.10 (RXD/15), U2.12 (R1OUT)
UART_TX: U1.8 (TXD/14), U2.11 (T1IN)

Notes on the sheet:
Power Regulator
I2C Port
Power source select jumper JP7: 1-2 -> Power provided trough onboard regulator circuit (J5 Input range: 7-35V) 2-3 -> Bypass regulator circuit (Make sure to use apropriate quality 5V external power supply) OPEN -> Power is provided trough Raspberry Pi USB power input connector
GPIB bus adapter type: Pasive: Populate RN1, RN2, RN3 and RN4 Active: Populate U3, U4, C6, C7
GPIB Interface driver
I_sat > 3,5A I_rms > 3A
RS232 enabling CTS and RTS lines: Close Jumpers JP1, JP2, JP4 and JP5 (CTS_EN and RTS_EN) Open jumper JP3 pos. 1-2 and close pos. 2-3 (DIO3_RT) (this rewires GPIB DIO3 line from GPIO16 to GPIO21)
RS232 Interface Driver
RPi Connections
Cooling Fan

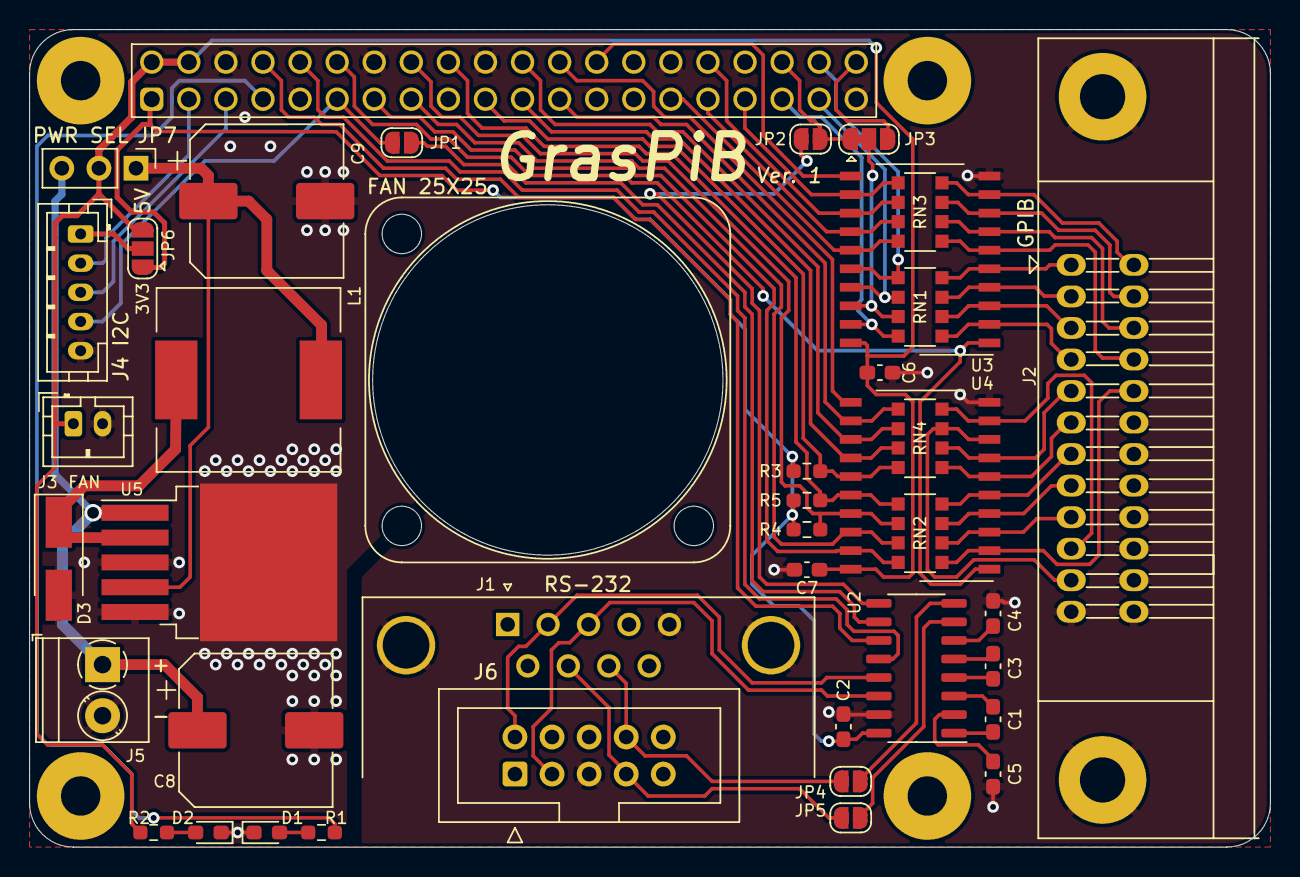
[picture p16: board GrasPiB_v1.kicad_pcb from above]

Board: 2 copper layers, 85.0 x 56.0 mm, 43 parts (0 on the bottom side), 66 nets.

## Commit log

2021-12-30 Add initial design files and documentation
    [GrasPiB_v1-B_Cu.gbr, GrasPiB_v1-B_Mask.gbr, GrasPiB_v1-B_Paste.gbr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]
2022-01-13 Rewire RTS and CTS signals the correct way
    [GrasPiB_v1-B_Cu.gbr, GrasPiB_v1-B_Mask.gbr, GrasPiB_v1-B_Paste.gbr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]
2022-01-13 Update gerber files
    [GrasPiB_v1-B_Cu.gbr, GrasPiB_v1-B_Mask.gbr, GrasPiB_v1-B_Paste.gbr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]
2022-03-12 Convert design files to KiCAD 6
    [GrasPiB_v1-B_Cu.gbr, GrasPiB_v1-B_Mask.gbr, GrasPiB_v1-B_Paste.gbr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]
2022-03-12 Add arduino adapter board design files
    [GrasPiB_AR488_Adapter-B_Cu.gbr, GrasPiB_AR488_Adapter-B_Mask.gbr, GrasPiB_AR488_Adapter-B_SilkS.gbr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]
